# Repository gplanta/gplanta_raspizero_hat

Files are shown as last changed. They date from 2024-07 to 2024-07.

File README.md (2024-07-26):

# gplanta_raspizero_hat
Project Logo
## Overview

This project is a Raspberry Pi Zero Sensor and PWM uHAT.
Python App coming soon.

## Features

- **ONEWIRE**: Connect ONEWIRE Sensors.
- **I2C**: Connect I2C Sensors.
- **PWM**: Control 2 PWM signals. PWM1 only GND/PWM. PWM2 with 12V DC input and rpm readout.
- **RELAIS**: Connect 4 Relais.
- **SPI**: Connect a SPI Display.

## BOM

- 3x	1k Resistor 0603
- 1x	3k3 Resistor 0603
- 2x	3.9k Resistor 0603
- 1x	4k7 Resistor 0603
- 1x	100n Capacitor 0603
- 1x	680uF Capacitor 1206
- 1x	CAT24C256
- 1x	PJ-102A
- 2x	IRF7319TRPBF
- 1x	CONN_47053-1000_MOL
- 1x	PinHeader_1x08_P2.54mm_Vertical
- 1x	PinHeader_1x04_P2.54mm_Vertical
- 1x	PinHeader_1x06_P2.54mm_Vertical
- 1x	PinHeader_1x03_P2.54mm_Vertical
- 1x	PinSocket_2x20_P2.54mm_Vertical
- 1x	TerminalBlock_MetzConnect_Type059_RT06302HBWC_1x02_P3.50mm_Horizontal
- 1x	TerminalBlock_MetzConnect_Type059_RT06303HBWC_1x03_P3.50mm_Horizontal
- 1x	TerminalBlock_MetzConnect_Type059_RT06304HBWC_1x04_P3.50mm_Horizontal

## PCB Overview
Side:
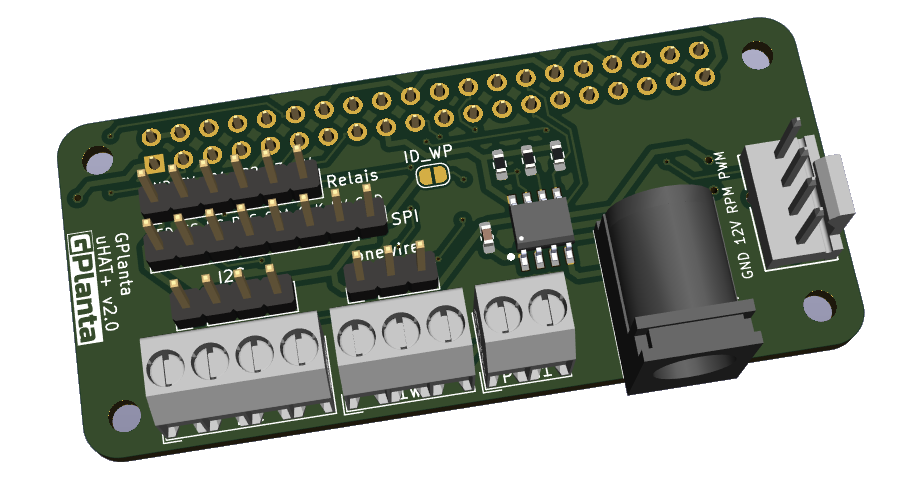
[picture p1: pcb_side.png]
Side Logo


Front:
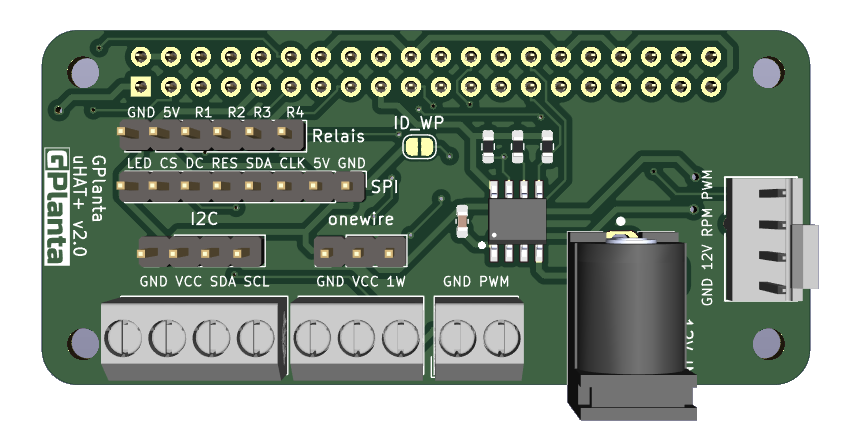
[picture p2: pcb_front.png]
Front Logo


Back:
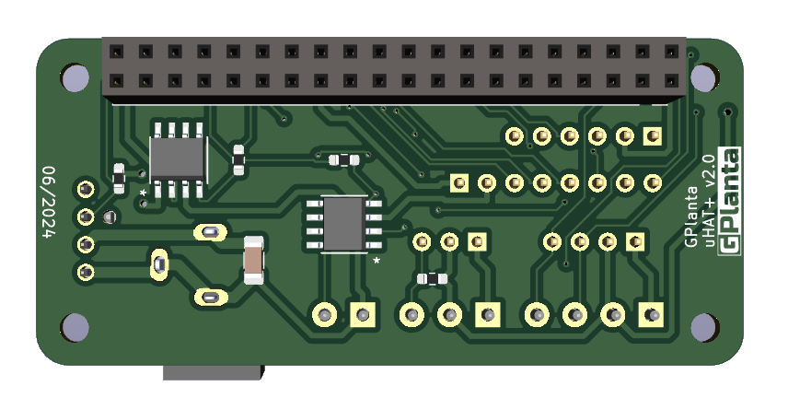
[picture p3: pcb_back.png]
Back Logo


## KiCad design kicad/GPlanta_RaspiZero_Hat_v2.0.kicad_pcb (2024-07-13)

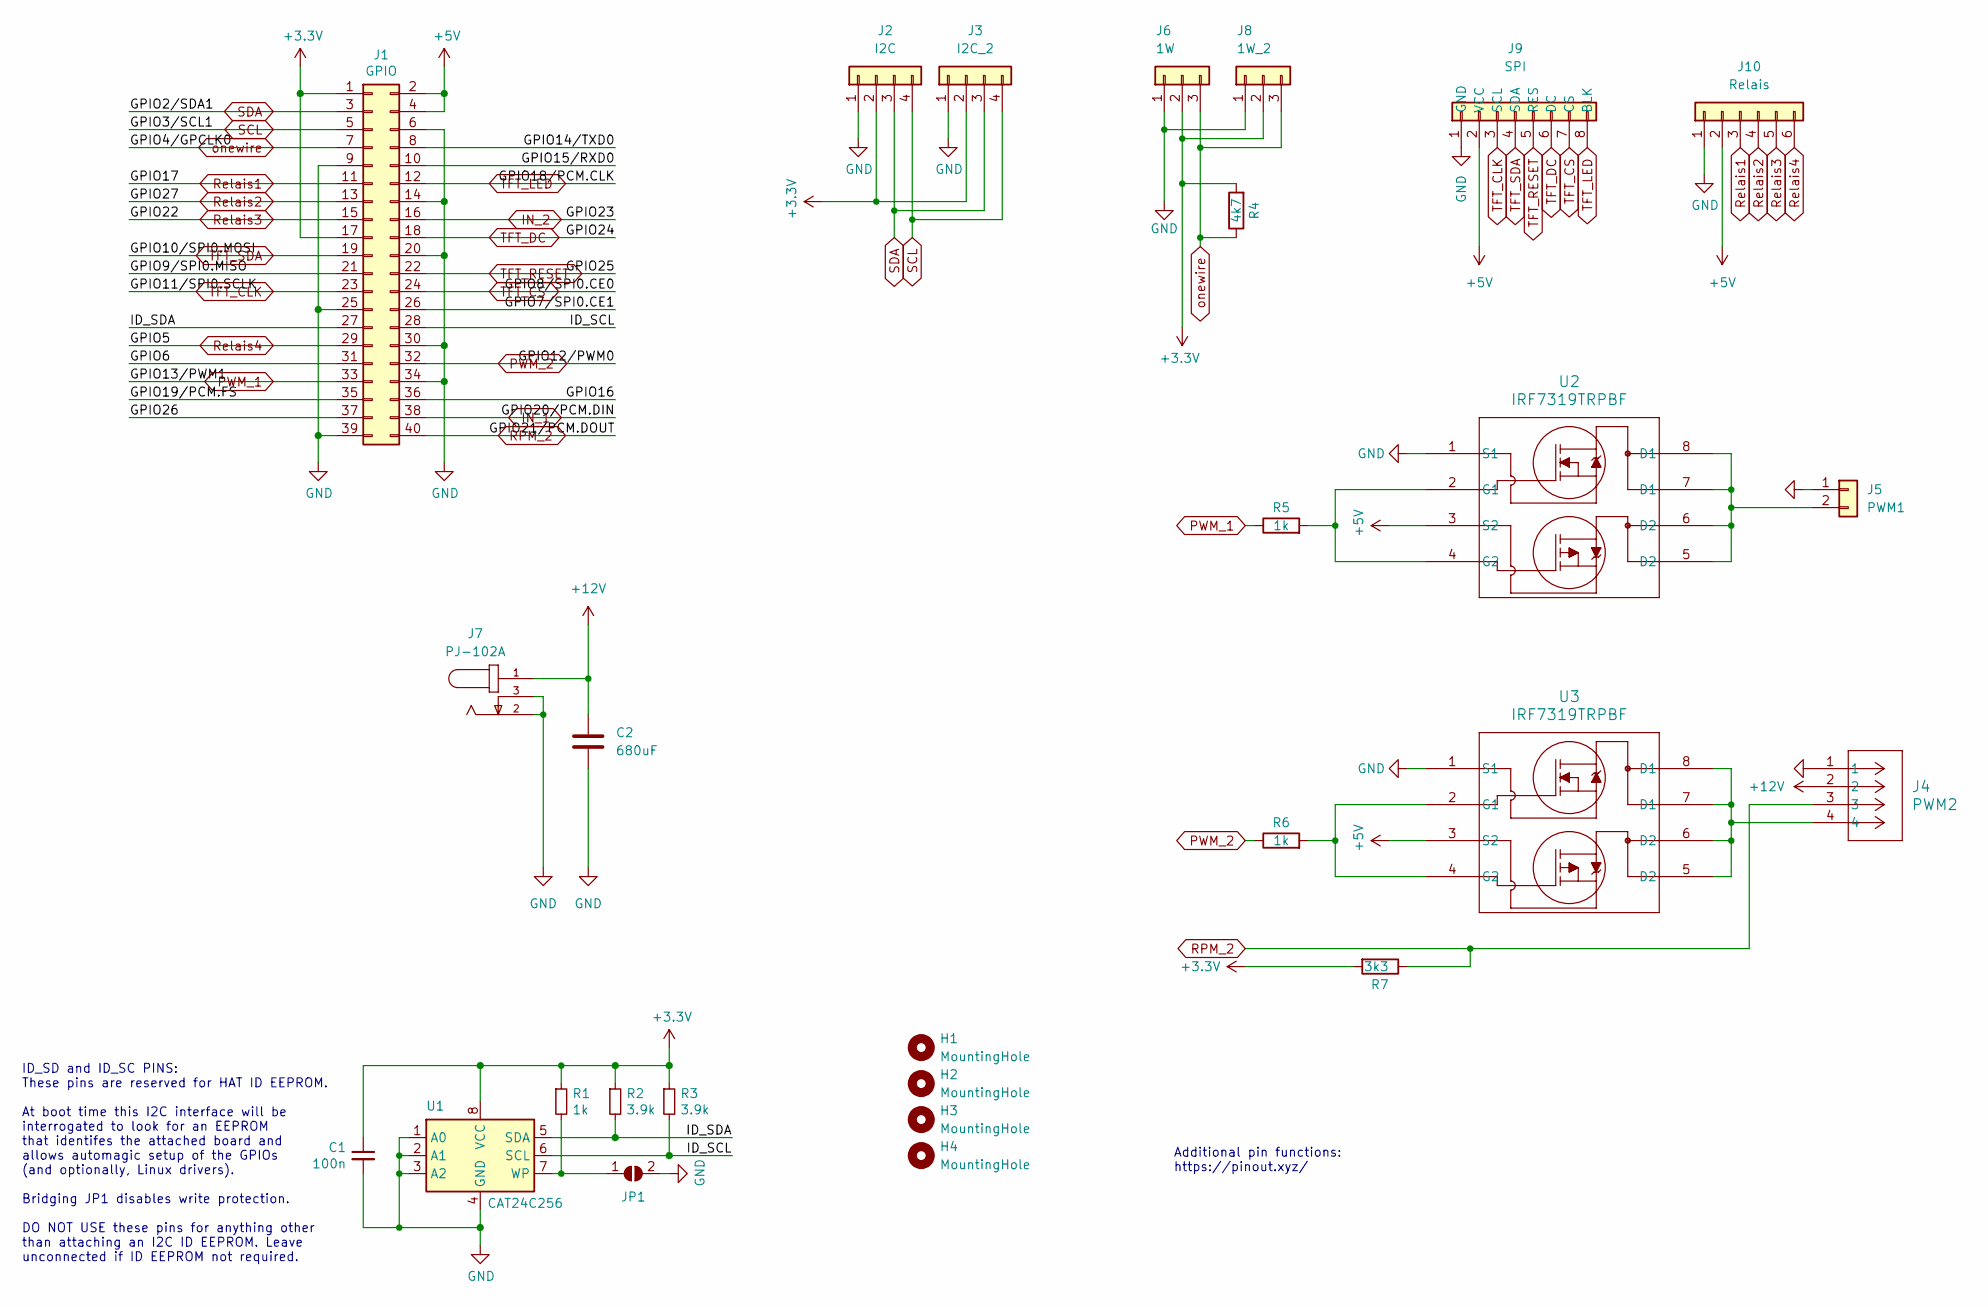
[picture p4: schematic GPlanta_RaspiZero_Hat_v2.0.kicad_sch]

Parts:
C1: 100n; C_0603_1608Metric_Pad1.08x0.95mm_HandSolder
C2: 680uF; C_1206_3216Metric_Pad1.33x1.80mm_HandSolder
H1, H2, H3, H4: MountingHole; MountingHole_2.7mm_M2.5
J1: GPIO; PinSocket_2x20_P2.54mm_Vertical
J2: I2C; TerminalBlock_MetzConnect_Type059_RT06304HBWC_1x04_P3.50mm_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
J3: I2C_2; PinHeader_1x04_P2.54mm_Vertical
J4: PWM2; CONN_47053-1000_MOL
J5: PWM1; TerminalBlock_MetzConnect_Type059_RT06302HBWC_1x02_P3.50mm_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
J6: 1W; TerminalBlock_MetzConnect_Type059_RT06303HBWC_1x03_P3.50mm_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
J7: PJ-102A; CUI_PJ-102A; PART_REV 1.03
J8: 1W_2; PinHeader_1x03_P2.54mm_Vertical
J9: SPI; PinHeader_1x08_P2.54mm_Vertical
J10: Relais; PinHeader_1x06_P2.54mm_Vertical
JP1: ID_WP; SolderJumper-2_P1.3mm_Open_RoundedPad1.0x1.5mm
R1, R5, R6: 1k; R_0603_1608Metric_Pad0.98x0.95mm_HandSolder
R2, R3: 3.9k; R_0603_1608Metric_Pad0.98x0.95mm_HandSolder
R4: 4k7; R_0603_1608Metric_Pad0.98x0.95mm_HandSolder
R7: 3k3; R_0603_1608Metric_Pad0.98x0.95mm_HandSolder
U1: CAT24C256; SOIC8-1.27-5X4MM
U2, U3: IRF7319TRPBF; TRANS_IRF7103TRPBF_INF

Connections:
+3V3: C1.1, J1.1, J1.17, J2.2, J3.2, J6.2, J8.2, R1.1, R2.1, R3.1, R4.2, R7.2, U1.8 (VCC)
+5V: J1.2, J1.4, J9.2 (VCC), J10.2, U2.3 (S2), U3.3 (S2)
+12V: C2.1, J4.2, J7.1
/GPIO6: J1.31
/GPIO7/SPI0.CE1: J1.26
/GPIO9/SPI0.MISO: J1.21
/GPIO14/TXD0: J1.8
/GPIO15/RXD0: J1.10
/GPIO16: J1.36
/GPIO19/PCM.FS: J1.35
/GPIO26: J1.37
/ID_SCL: J1.28, R3.2, U1.6 (SCL)
/ID_SDA: J1.27, R2.2, U1.5 (SDA)
GND: C1.2, C2.2, J1.6, J1.9, J1.14, J1.20, J1.25, J1.30, J1.34, J1.39, J2.1, J3.1, J4.1, J5.1, J6.1, J7.2, J7.3, J8.1, J9.1 (GND), J10.1, JP1.2 (B), U1.1 (A0), U1.2 (A1), U1.3 (A2), U1.4 (GND), U2.1 (S1), U3.1 (S1)
IN_1: J1.38
IN_2: J1.16
unnamed: J4.4, U3.5 (D2), U3.6 (D2), U3.7 (D1), U3.8 (D1)
unnamed: J5.2, U2.5 (D2), U2.6 (D2), U2.7 (D1), U2.8 (D1)
unnamed: JP1.1 (A), R1.2, U1.7 (WP)
unnamed: R5.2, U2.2 (G1), U2.4 (G2)
unnamed: R6.2, U3.2 (G1), U3.4 (G2)
PWM_1: J1.33, R5.1
PWM_2: J1.32, R6.1
RPM_2: J1.40, J4.3, R7.1
Relais1: J1.11, J10.3
Relais2: J1.13, J10.4
Relais3: J1.15, J10.5
Relais4: J1.29, J10.6
SCL: J1.5, J2.4, J3.4
SDA: J1.3, J2.3, J3.3
TFT_CLK: J1.23, J9.3 (SCL)
TFT_CS: J1.24, J9.7 (CS)
TFT_DC: J1.18, J9.6 (DC)
TFT_LED: J1.12, J9.8 (BLK)
TFT_RESET: J1.22, J9.5 (RES)
TFT_SDA: J1.19, J9.4 (SDA)
onewire: J1.7, J6.3, J8.3, R4.1

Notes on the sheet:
ID_SD and ID_SC PINS: These pins are reserved for HAT ID EEPROM. At boot time this I2C interface will be interrogated to look for an EEPROM that identifes the attached board and allows automagic setup of the GPIOs (and optionally, Linux drivers). Bridging JP1 disables write protection. DO NOT USE t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
Additional pin functions: https://pinout.xyz/

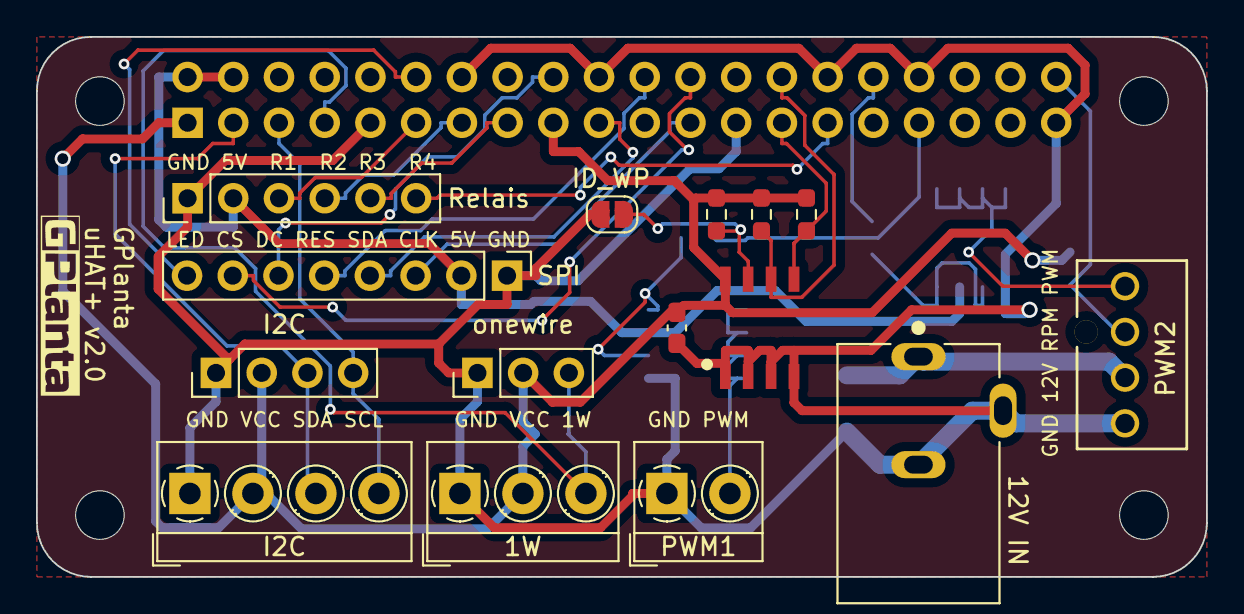
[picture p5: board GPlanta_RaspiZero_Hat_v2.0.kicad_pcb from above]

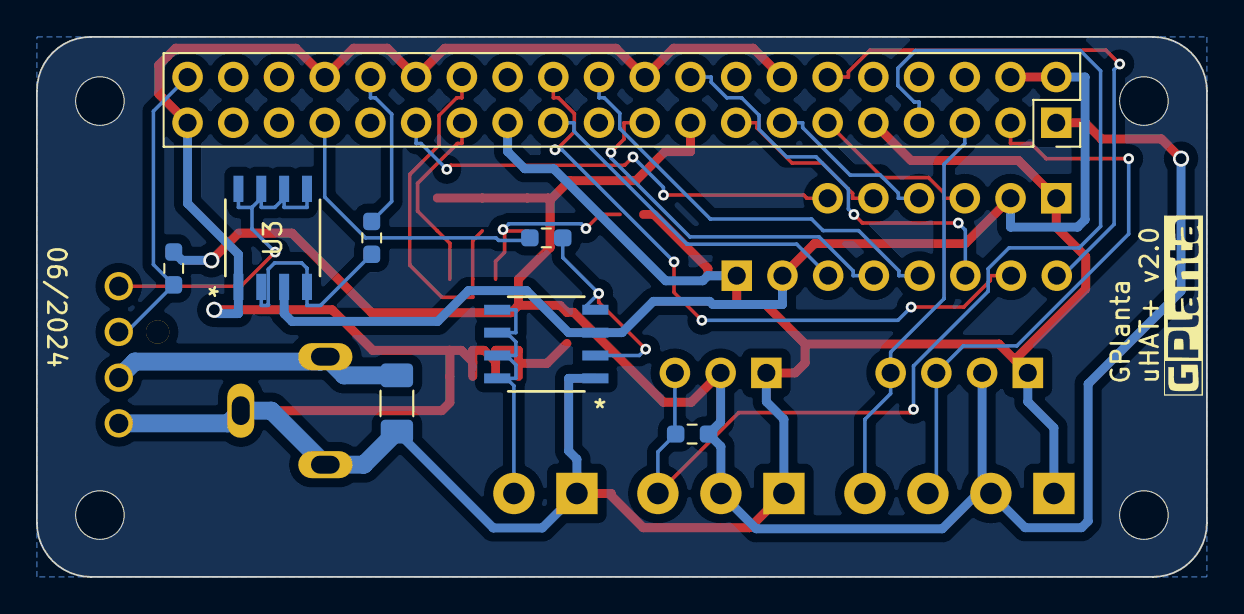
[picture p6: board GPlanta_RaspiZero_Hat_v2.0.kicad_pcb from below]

Board: 2 copper layers, 65.0 x 30.0 mm, 29 parts (9 on the bottom side), 27 nets.

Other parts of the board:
G1, G2: LOGO; gplanta_small
